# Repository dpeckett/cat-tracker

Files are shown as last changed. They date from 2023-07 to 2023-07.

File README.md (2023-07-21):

# Cat Tracker

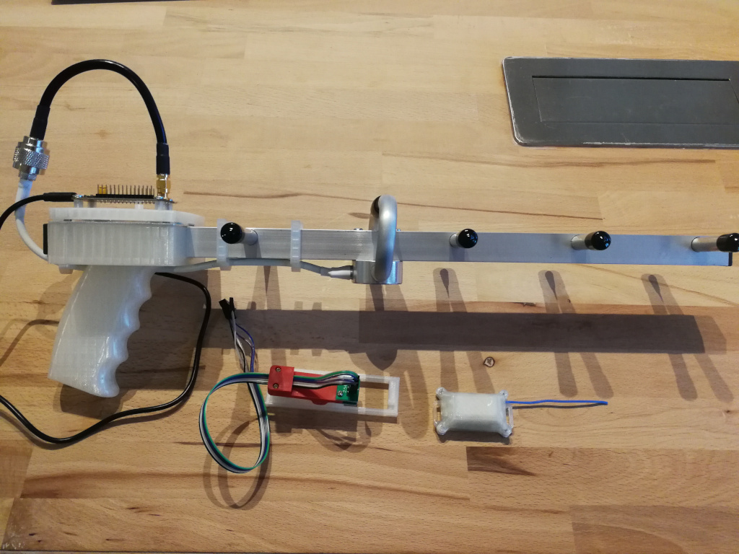
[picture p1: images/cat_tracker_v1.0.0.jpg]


An active RFID system for locating free roaming pets / wildlife. Uses a compact handheld radio direction finding receiver rather than GPS (due to power budget and the need for real-time updates). Kind of a modern take on a traditional wildlife tracker.

## Backstory

My wife and I adopted a free roaming snow bengal cat from a former neighbor. She's a very naughty cat and often decides she wants to spend extended time away from us in the giant wooded park next door.

I've spent many a late night walking in the woods with a kibble bag trying to get her to come home for dinner. I can usually locate her but it's a gigantic PITA.

It would be nice to have a real time GPS position but the commercial tracking collars are bulky (she's a tiny cat), expensive (ongoing fees), and have limited battery life. Of course there is the air tag and tile products, which I think are probably amazing in an urban area but our cat is often found in the dense woods far away from other people.

None of the existing solutions satisfied me so I decided to build my own. It had to be very compact, have a long battery life (months or years), and no ongoing costs.

## Notes

### Edit the Radio Configuration For Your Region

If you are outside the EU you will probably need to modify the radio configuration in [firmware/CatTracker/Base/subghz_radio.h](./firmware/CatTracker/Base/subghz_radio.h) to match your legislative region.

### To Unlock A STM32WLExx

Telnet into the OpenOCD server:

```
telnet localhost 4444
```

And run the following commands:

```
stm32l4x unlock 0
# Clear FLASH_OPTR
stm32l4x option_write 0 0x20 0xbffff0aa
# Power cycle the device
halt
stm32l4x mass_erase 0
```

### To Read The Unique ID From A STM32WLExx

Telnet into the OpenOCD server:

```
telnet localhost 4444
```

And run the following commands:

```
mdw 0x1FFF7590
```

## Errata

### EBYTE E77-900M22S Dev Boards

My boards arrived with a capacitor missing from the lowpass filter before the SMA jack. This meant the antenna jack was completely disconnected.

### PCB

The footprint for the battery holder needs a larger keep out area so that the center pad makes good contact. I temporarily resolved this by raising the pad with some additional solder.

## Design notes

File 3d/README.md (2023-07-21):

# Solid Models

This directory contains the solid models for the 3D printed parts of the
project. The models are designed in [OpenSCAD](http://www.openscad.org/).

## Parts

The following parts are included:

* `programming_jig.scad` - A jig to hold the PCB in place while programming (using a modified [3x2 pogo pin clip](https://aliexpress.com/item/1005003705632078.html)).
* `tracker_case.scad` - A case for holding the tracker PCB and battery.
* `tracker_case_lid.scad` - A lid for the tracker case.

## Notes

The lid and case of the tracker are affixed using four 2.9x6.5mm self-tapping screws.

To waterproof the tracker case I basically coated the entire assembly (and lid mating surface) in a layer of two-part silicone rubber. You could print the tracker out of resin but you'd have to design some kind of gasket (perhaps in a future revision).

## License

The models are licensed under the [Creative Commons Zero v1.0 Universal](https://creativecommons.org/publicdomain/zero/1.0/) license.

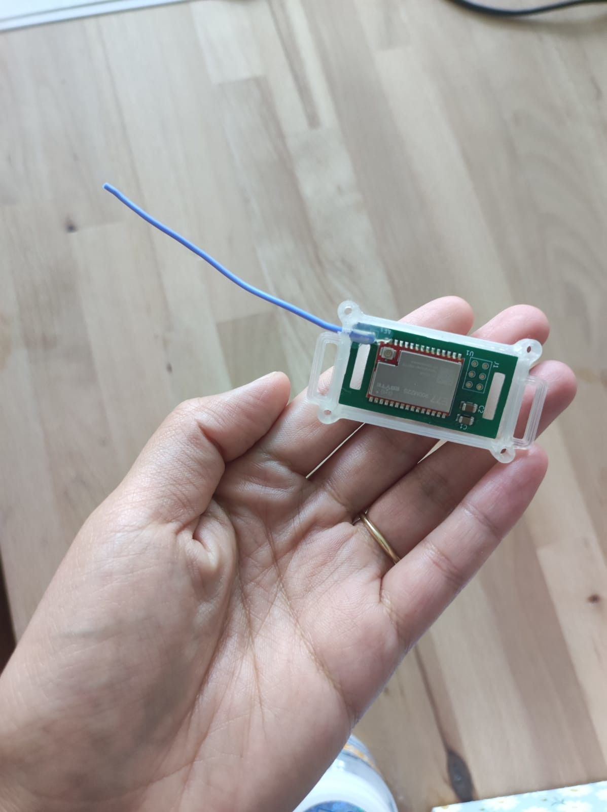
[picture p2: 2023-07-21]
images/cat_tracker_pcb_v1.0.0.jpg

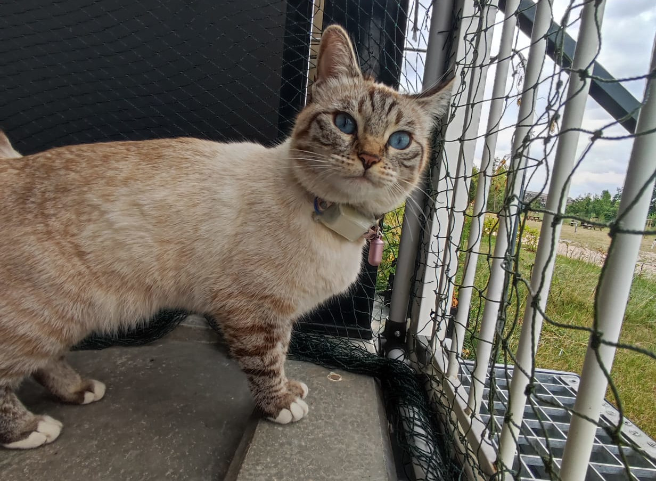
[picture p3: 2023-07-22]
images/cat_with_tracker_v1.0.0.jpg

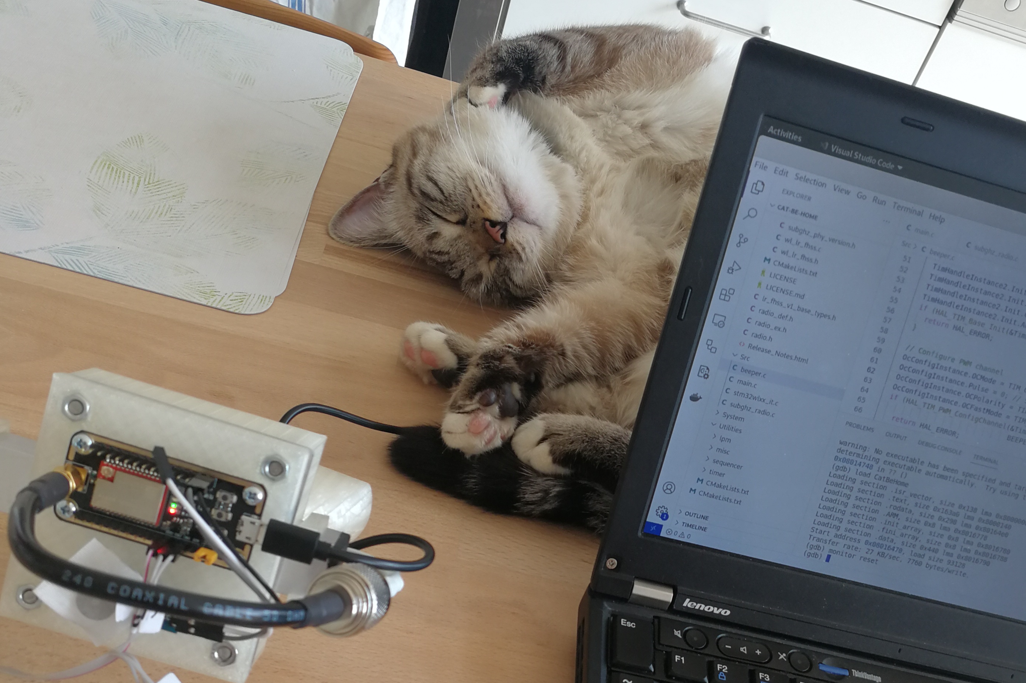
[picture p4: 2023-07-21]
images/cat_v1.0.0.jpg

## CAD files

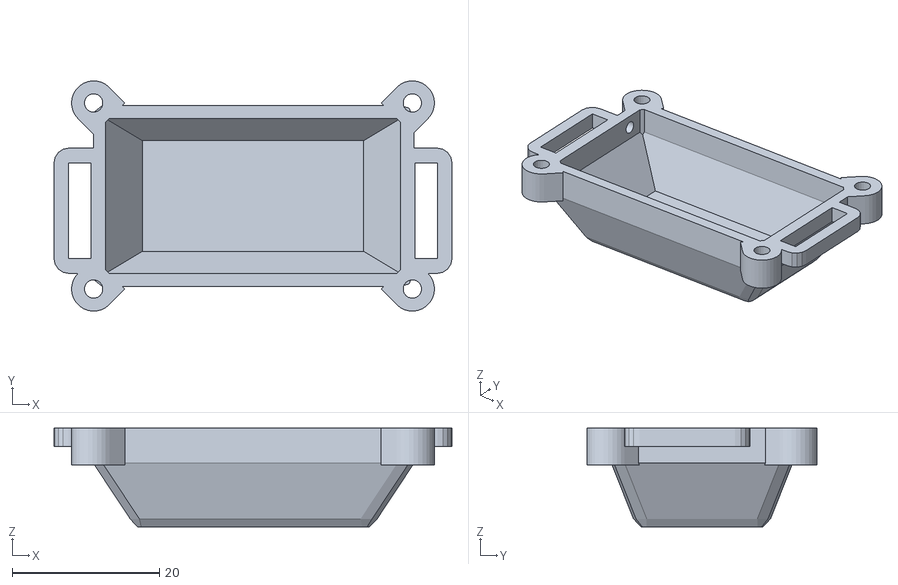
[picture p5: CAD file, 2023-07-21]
3d/tracker_case.stl
54.0 x 31.2 x 13.4

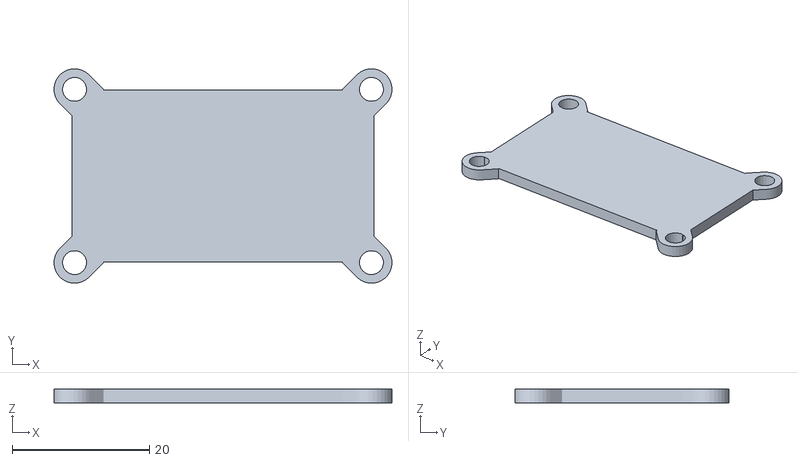
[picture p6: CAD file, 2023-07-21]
3d/tracker_case_lid.stl
49.2 x 31.2 x 2.00

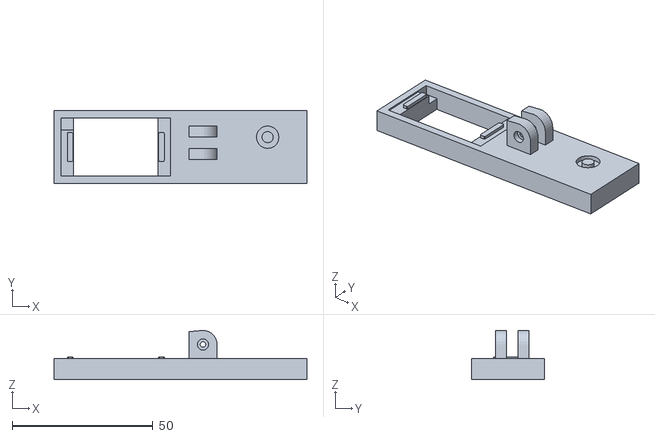
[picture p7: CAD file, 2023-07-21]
3d/programming_jig.stl
90.0 x 26.0 x 17.5

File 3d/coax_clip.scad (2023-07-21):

thickness = 3;
teeth_engage=2;
major_dim = 20.1;
coax_hole = 5.5;

extendo = 0;

linear_extrude(height=6) union() {
    difference() {
      square([major_dim + 2*thickness, major_dim + thickness]);
      translate([thickness, 0, 0]) square([major_dim, major_dim]);
      translate([major_dim/2 + thickness - coax_hole/2, major_dim, 0]) square([coax_hole, thickness]);
    }

    polygon([[0, 0], [thickness + teeth_engage, 0], [thickness + teeth_engage, -0.5*thickness], [0, -2*thickness]]);

    polygon([[major_dim + 2*thickness, 0], [(major_dim + 2*thickness) - thickness - teeth_engage, 0], [(major_dim + 2*thickness) - thickness - teeth_engage, -0.5*thickness], [major_dim + 2*thickness, -2*thickness]]);

    translate([major_dim/2 + thickness, extendo + major_dim+thickness, 0]) difference() {
        circle(d=coax_hole + 2*thickness, $fn = 20);
        circle(d=coax_hole, $fn = 20);
        translate([-(coax_hole + 2*thickness)/2, -2 *thickness]) square([coax_hole + 2*thickness, 2*thickness]);
    }
    
    translate([major_dim/2 - coax_hole/2, major_dim+thickness, 0])square([thickness, extendo]);
    
    translate([major_dim/2 + coax_hole/2 + thickness, major_dim+thickness, 0])square([thickness, extendo]);
}

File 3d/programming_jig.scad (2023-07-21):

difference() {
  cube([90, 26, 7.5]);
    
  translate([2.5, (26-20.5)/2, 7]) cube([39, 20.5, 0.5]);
  translate([7, (26-20.5)/2, 0]) cube([30, 20.5, 7.5]);
    
  translate([2.5, 19, 4]) cube([4.5, 4.5, 3]);
    
  translate([76, 16.5, 6])difference() {
    cylinder(d=8, h=1.5, $fn=20);
    cylinder(d=4, h=1.5, $fn=20);
  }
}

minkowski() {
  translate([5.25, 8.25, 7]) cube([1, 9.5, 0.5]);
  cylinder(d=1, h=0.5, $fn=10);
}

minkowski() {
  translate([5 + 32 + 0.75, 8.25, 7]) cube([1, 9.5, 0.5]);
  cylinder(d=1, h=0.5, $fn=10);
}

translate([53, 8.5, 7.5]) difference() {
  union() {
    translate([0, 0, 5]) rotate(a = [-90, 0, 0]) cylinder(d = 10, h = 12, $fn = 30);
    translate([-5, 0, 0]) cube([10, 12, 5]);
   
    // limit the rotation to 5 deg, to keep the spring retained.
    x = 5*(1 - tan(5));
    translate([0, 0, 5]) rotate(a = [-90, -180, 0])  linear_extrude(height = 12) polygon([[0, 0], [5, 0], [5, x], [0, 5]]);
  }
  
  translate([0, 0, 5]) rotate(a = [-90, 0, 0]) cylinder(d = 4, h = 2, $fn = 30);
  
  translate([0, 0, 5]) rotate(a = [-90, 0, 0]) cylinder(d = 2, h = 12, $fn = 16);
  translate([-5, 4, 0]) cube([10,4,10]);
}

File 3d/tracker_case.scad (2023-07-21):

thickness = 2;

case();
//lid();

module lid() {
  difference() {
    translate([0, 0, thickness/2]) cube([40 + 2*thickness, 21 + 2*thickness, thickness], center=true);
      
     // clearance for the screw ears.
    translate([-21.25, 12.25, 0]) cylinder(d = 3, h = thickness, $fn = 10);
    translate([-21.25, -12.25, 0]) cylinder(d = 3, h = thickness, $fn = 10);
    translate([21.25, 12.25, 0]) cylinder(d = 3, h = thickness, $fn = 10);
    translate([21.25, -12.25, 0]) cylinder(d = 3, h = thickness, $fn = 10);
  }
 
  // Screw ears
  translate([-19.5, 10.5, 0]) rotate(a = [0, 0, 45]) screw_ear(height = thickness, diameter = 3.5);
  translate([-19.5, -10.5, 0]) rotate(a = [0, 0, 135]) screw_ear(height = thickness, diameter = 3.5);
  translate([19.5, 10.5, 0]) rotate(a = [0, 0, -45]) screw_ear(height = thickness, diameter = 3.5);
  translate([19.5, -10.5, 0]) rotate(a = [0, 0, -135]) screw_ear(height = thickness, diameter = 3.5);
}

module case() {
  difference() {
    union() {
      minkowski() {
        union() {
          inner();
          translate([0, 0, 7.5 + (4+thickness)/2])        cube([40, 21, 4 + thickness], center = true);
        }
        sphere(r =  thickness);
      }
    }
  
    inner();
  
    // slice the top off clean.
    translate([0, 0, 7.5 + 2 * thickness + (11/2)]) cube([50, 50, 11], center = true);

    // clearance for the screw ears.
    translate([-21.25, 12.25, 7]) cylinder(d = 3, h = 5, $fn = 10);
    translate([-21.25, -12.25, 7]) cylinder(d = 3, h = 5, $fn = 10);
    translate([21.25, 12.25, 7]) cylinder(d = 3, h = 5, $fn = 10);
    translate([21.25, -12.25, 7]) cylinder(d = 3, h = 5, $fn = 10);
  
    // The antenna hole.
    translate([-21.75, 7.5, 9.5])rotate(a = [0, 90, 0]) cylinder(d = 1.9, h = thickness, $fn = 30);
  }

  // Screw ears
  translate([-19.5, 10.5, 6.5]) rotate(a = [0, 0, 45]) screw_ear();
  translate([-19.5, -10.5, 6.5]) rotate(a = [0, 0, 135]) screw_ear();
  translate([19.5, 10.5, 6.5]) rotate(a = [0, 0, -45]) screw_ear();
  translate([19.5, -10.5, 6.5]) rotate(a = [0, 0, -135]) screw_ear();

  translate([-23.5, -2, 9]) collar_ring(height=2.5);
  translate([23.5, -2, 9]) rotate(a = [0, 0, 180]) collar_ring(height=2.5);
}

module inner() {
  hull() {
    cube([30, 15, 0.1], center = true);
    translate([0, 0, 7.5 + 4/2]) cube([40, 21, 4], center = true);
  }
}

module screw_ear(height = 5, diameter = 2.5) {
    difference() {
      union() {
        translate([0, 6/2, 0]) cylinder(d = 6, h = height, $fn=30);
        translate([-6/2, 0, 0]) cube([6, 6/2, height]);
      }
      
      translate([0, 6/2, 0]) cylinder(d = diameter, h = height, $fn = 20);
    }
}

module collar_ring(height = 5) {
  linear_extrude(height = height) difference() {
    union() {
      minkowski() {
        square([3, 13], center=true);
        circle(r = thickness, $fn = 16);
      }
      translate([0, -(13 + 2*thickness)/2, 0]) square([3/2 + thickness, 13 + 2*thickness]);
    }
    square([3, 13], center=true);
  }
}

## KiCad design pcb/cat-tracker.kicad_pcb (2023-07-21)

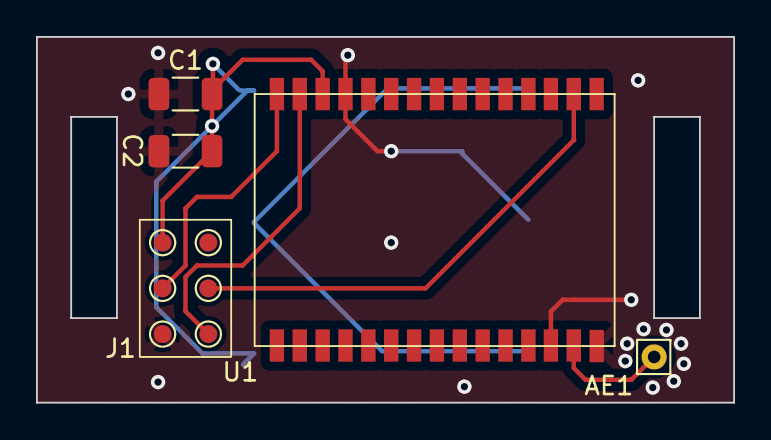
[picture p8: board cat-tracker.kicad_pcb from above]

Board: 2 copper layers, 38.7 x 20.3 mm, 5 parts (0 on the bottom side), 6 nets.

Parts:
AE1: Antenna; Pin_D0.7mm_L6.5mm_W1.8mm_FlatFork
C1: 1uF; C_1206_3216Metric
C2: 10uF; C_1206_3216Metric
J1: SWD
U1: E07-900M10S

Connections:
GND: C1.2, C2.2, J1.3, U1.13 (GND), U1.15 (GND), U1.27 (GND)
unnamed: AE1.1 (A), U1.14 (ANT)
unnamed: J1.2, U1.30 (SWCLK)
unnamed: J1.4, U1.29 (SWDIO)
unnamed: J1.5, U1.17 (NRST)
VDD: C1.1, C2.1, J1.1, U1.28 (VDD)

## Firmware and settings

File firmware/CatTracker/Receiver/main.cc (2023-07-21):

#include <array>
#include <cstdlib>
#include <cstring>

#include "main.h"
#include "packet_handler.h"
#include "subghz_radio.h"
#include "time_util.h"
#include "uart.h"

namespace CatTracker {

void radioProcessEvent();
void receiveNextPacket(void *Context);

HAL_StatusTypeDef configureSystemClock();

UTIL_TIMER_Object_t RxTimer;

extern "C" int main() {
  if (HAL_Init() != HAL_OK) {
    Error_Handler();
  }

  if (configureSystemClock() != HAL_OK) {
    Error_Handler();
  }

  // Initialize timer and RTC.
  UTIL_TIMER_Init();

  if (UART::init() != HAL_OK) {
    Error_Handler();
  }

  if (SUBGHZRadio::init() != HAL_OK) {
    Error_Handler();
  }

  // Register radio event handler.
  UTIL_SEQ_RegTask((1 << CFG_SEQ_Task_SubGHz_ProcessEvent), UTIL_SEQ_RFU,
                   radioProcessEvent);

  printf("Listening for beacons...\r\n");

  // Kick off the radio event loop.
  receiveNextPacket(nullptr);

  for (;;) {
    UTIL_SEQ_Run(UTIL_SEQ_DEFAULT);
  }

  return 0;
}

void radioProcessEvent() {
  const auto EventType = SUBGHZRadio::getEventType();
  const auto PacketHandler = getPacketHandler();
  SUBGHZRadio::Packet TxPacket;

  if (EventType == SUBGHZRadio::EventType::Rx) {
    if (PacketHandler(SUBGHZRadio::getReceivedPacket(), &TxPacket)) {
      SUBGHZRadio::sendPacket(&TxPacket);
      return;
    }
  }

  UTIL_TIMER_Create(&RxTimer, 0, UTIL_TIMER_ONESHOT, receiveNextPacket,
                    nullptr);
  UTIL_TIMER_Start(&RxTimer);
}

void receiveNextPacket(void *Context) { SUBGHZRadio::receivePacket(0); }

HAL_StatusTypeDef configureSystemClock() {
  RCC_OscInitTypeDef RCC_OscInitStruct = {0};
  RCC_ClkInitTypeDef RCC_ClkInitStruct = {0};

  // Configure LSE Drive Capability.
  HAL_PWR_EnableBkUpAccess();
  __HAL_RCC_LSEDRIVE_CONFIG(RCC_LSEDRIVE_LOW);

  // Configure the main internal regulator output voltage.
  __HAL_PWR_VOLTAGESCALING_CONFIG(PWR_REGULATOR_VOLTAGE_SCALE1);

  // Initializes the CPU, AHB and APB busses clocks.
  RCC_OscInitStruct.OscillatorType =
      RCC_OSCILLATORTYPE_HSE | RCC_OSCILLATORTYPE_LSE;
  RCC_OscInitStruct.HSEState = RCC_HSE_ON;
  RCC_OscInitStruct.LSEState = RCC_LSE_ON;
  RCC_OscInitStruct.HSEDiv = RCC_HSE_DIV1;
  RCC_OscInitStruct.PLL.PLLState = RCC_PLL_ON;
  RCC_OscInitStruct.PLL.PLLSource = RCC_PLLSOURCE_HSE;
  RCC_OscInitStruct.PLL.PLLM = RCC_PLLM_DIV2;
  RCC_OscInitStruct.PLL.PLLN = 12;
  RCC_OscInitStruct.PLL.PLLP = RCC_PLLP_DIV2;
  RCC_OscInitStruct.PLL.PLLR = RCC_PLLR_DIV4;
  RCC_OscInitStruct.PLL.PLLQ = RCC_PLLQ_DIV2;
  if (HAL_RCC_OscConfig(&RCC_OscInitStruct) != HAL_OK) {
    return HAL_ERROR;
  }

  // Configure the SYSCLKSource, HCLK, PCLK1 and PCLK2 clocks dividers.
  RCC_ClkInitStruct.ClockType = RCC_CLOCKTYPE_HCLK3 | RCC_CLOCKTYPE_HCLK |
                                RCC_CLOCKTYPE_SYSCLK | RCC_CLOCKTYPE_PCLK1 |
                                RCC_CLOCKTYPE_PCLK2;
  RCC_ClkInitStruct.SYSCLKSource = RCC_SYSCLKSOURCE_PLLCLK;
  RCC_ClkInitStruct.AHBCLKDivider = RCC_SYSCLK_DIV1;
  RCC_ClkInitStruct.APB1CLKDivider = RCC_HCLK_DIV1;
  RCC_ClkInitStruct.APB2CLKDivider = RCC_HCLK_DIV1;
  RCC_ClkInitStruct.AHBCLK3Divider = RCC_SYSCLK_DIV1;
  if (HAL_RCC_ClockConfig(&RCC_ClkInitStruct, FLASH_LATENCY_2) != HAL_OK) {
    return HAL_ERROR;
  }

  // Ensure that MSI is wake-up system clock.
  __HAL_RCC_WAKEUPSTOP_CLK_CONFIG(RCC_STOP_WAKEUPCLOCK_MSI);

  return HAL_OK;
}

void Error_Handler() { HAL_NVIC_SystemReset(); }

} // namespace CatTracker

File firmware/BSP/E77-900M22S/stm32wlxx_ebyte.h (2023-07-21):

/*
 * Copyright (c) 2020-2021 STMicroelectronics.
 * All rights reserved.
 *
 * This software is licensed under terms that can be found in the LICENSE file
 * in the root directory of this software component.
 * If no LICENSE file comes with this software, it is provided AS-IS.
 */

#ifndef STM32WLXX_EBYTE_H
#define STM32WLXX_EBYTE_H

#ifdef __cplusplus
extern "C" {
#endif

#include "stm32wlxx_ebyte_conf.h"
#include "stm32wlxx_ebyte_errno.h"

#if (USE_BSP_COM_FEATURE > 0)
#if (USE_COM_LOG > 0)
#ifndef __GNUC__
#include "stdio.h"
#endif
#endif
#endif

typedef enum {
  LED1 = 0,
  LED2 = 1,
  LED3 = 2,
  /* Color led aliases */
  LED_BLUE = LED1,
  LED_GREEN = LED2,
  LED_RED = LED3
} Led_TypeDef;

typedef enum {
  BUTTON_SW1 = 0,
  BUTTON_SW2 = 1,
  BUTTON_SW3 = 2,
} Button_TypeDef;

typedef enum { BUTTON_MODE_GPIO = 0, BUTTON_MODE_EXTI = 1 } ButtonMode_TypeDef;

#if (USE_BSP_COM_FEATURE > 0)
typedef enum { COM1 = 0U, COMn } COM_TypeDef;

typedef enum {
  COM_STOPBITS_1 = UART_STOPBITS_1,
  COM_STOPBITS_2 = UART_STOPBITS_2,
} COM_StopBitsTypeDef;

typedef enum {
  COM_PARITY_NONE = UART_PARITY_NONE,
  COM_PARITY_EVEN = UART_PARITY_EVEN,
  COM_PARITY_ODD = UART_PARITY_ODD,
} COM_ParityTypeDef;

typedef enum {
  COM_HWCONTROL_NONE = UART_HWCONTROL_NONE,
  COM_HWCONTROL_RTS = UART_HWCONTROL_RTS,
  COM_HWCONTROL_CTS = UART_HWCONTROL_CTS,
  COM_HWCONTROL_RTS_CTS = UART_HWCONTROL_RTS_CTS,
} COM_HwFlowCtlTypeDef;

typedef enum {
  COM_WORDLENGTH_7B = UART_WORDLENGTH_7B,
  COM_WORDLENGTH_8B = UART_WORDLENGTH_8B,
  COM_WORDLENGTH_9B = UART_WORDLENGTH_9B,
} COM_WordLengthTypeDef;

typedef struct {
  uint32_t BaudRate;
  COM_WordLengthTypeDef WordLength;
  COM_StopBitsTypeDef StopBits;
  COM_ParityTypeDef Parity;
  COM_HwFlowCtlTypeDef HwFlowCtl;
} COM_InitTypeDef;

#if (USE_HAL_UART_REGISTER_CALLBACKS == 1)
typedef struct {
  pUART_CallbackTypeDef pMspInitCb;
  pUART_CallbackTypeDef pMspDeInitCb;
} BSP_COM_Cb_t;
#endif /* (USE_HAL_UART_REGISTER_CALLBACKS == 1) */
#endif /* (USE_BSP_COM_FEATURE > 0) */

typedef enum {
  ABSENT = 0,
  PRESENT = 1,
} Presence_TypeDef;

/**
 * @brief STM32WLXX EBYTE BSP Driver version number
 */
#define __STM32WLXX_EBYTE_BSP_VERSION_MAIN (0x01U) /*!< [31:24] main version   \
                                                    */
#define __STM32WLXX_EBYTE_BSP_VERSION_SUB1 (0x03U) /*!< [23:16] sub1 version   \
                                                    */
#define __STM32WLXX_EBYTE_BSP_VERSION_SUB2 (0x00U) /*!< [15:8]  sub2 version   \
                                                    */
#define __STM32WLXX_EBYTE_BSP_VERSION_RC                                       \
  (0x00U) /*!< [7:0]  release candidate */
#define __STM32WLXX_EBYTE_BSP_VERSION                                          \
  ((__STM32WLXX_EBYTE_BSP_VERSION_MAIN << 24) |                                \
   (__STM32WLXX_EBYTE_BSP_VERSION_SUB1 << 16) |                                \
   (__STM32WLXX_EBYTE_BSP_VERSION_SUB2 << 8) |                                 \
   (__STM32WLXX_EBYTE_BSP_VERSION_RC))

/**
 * @brief Define for STM32WLXX_EBYTE board
 */
#if !defined(USE_STM32WLXX_EBYTE)
#define USE_STM32WLXX_EBYTE
#endif

#define LEDn 3

#define LED1_PIN GPIO_PIN_5
#define LED1_GPIO_PORT GPIOB
#define LED1_GPIO_CLK_ENABLE() __HAL_RCC_GPIOB_CLK_ENABLE()
#define LED1_GPIO_CLK_DISABLE() __HAL_RCC_GPIOB_CLK_DISABLE()

#define LED2_PIN GPIO_PIN_4
#define LED2_GPIO_PORT GPIOB
#define LED2_GPIO_CLK_ENABLE() __HAL_RCC_GPIOB_CLK_ENABLE()
#define LED2_GPIO_CLK_DISABLE() __HAL_RCC_GPIOB_CLK_DISABLE()

#define LED3_PIN GPIO_PIN_3
#define LED3_GPIO_PORT GPIOB
#define LED3_GPIO_CLK_ENABLE() __HAL_RCC_GPIOB_CLK_ENABLE()
#define LED3_GPIO_CLK_DISABLE() __HAL_RCC_GPIOB_CLK_DISABLE()

#define LEDx_GPIO_CLK_ENABLE(__INDEX__)                                        \
  __HAL_RCC_GPIOB_CLK_ENABLE() /* All Led on same port */
#define LEDx_GPIO_CLK_DISABLE(__INDEX__)                                       \
  __HAL_RCC_GPIOB_CLK_DISABLE() /* All Led on same port */

#define BUTTONn 3

/**
 * @brief Key push-buttons
 */
#define BUTTON_SW1_PIN GPIO_PIN_0
#define BUTTON_SW1_GPIO_PORT GPIOA
#define BUTTON_SW1_GPIO_CLK_ENABLE() __HAL_RCC_GPIOA_CLK_ENABLE()
#define BUTTON_SW1_GPIO_CLK_DISABLE() __HAL_RCC_GPIOA_CLK_DISABLE()
#define BUTTON_SW1_EXTI_LINE EXTI_LINE_0
#ifdef CORE_CM0PLUS
#define BUTTON_SW1_EXTI_IRQn EXTI1_0_IRQn
#else
#define BUTTON_SW1_EXTI_IRQn EXTI0_IRQn
#endif
#define H_EXTI_0 hpb_exti[BUTTON_SW1]

#define BUTTON_SW2_PIN GPIO_PIN_1
#define BUTTON_SW2_GPIO_PORT GPIOA
#define BUTTON_SW2_GPIO_CLK_ENABLE() __HAL_RCC_GPIOA_CLK_ENABLE()
#define BUTTON_SW2_GPIO_CLK_DISABLE() __HAL_RCC_GPIOA_CLK_DISABLE()
#define BUTTON_SW2_EXTI_LINE EXTI_LINE_1
#ifdef CORE_CM0PLUS
#define BUTTON_SW2_EXTI_IRQn EXTI1_0_IRQn
#else
#define BUTTON_SW2_EXTI_IRQn EXTI1_IRQn
#endif
#define H_EXTI_1 hpb_exti[BUTTON_SW2]

#define BUTTON_SW3_PIN GPIO_PIN_4
#define BUTTON_SW3_GPIO_PORT GPIOA
#define BUTTON_SW3_GPIO_CLK_ENABLE() __HAL_RCC_GPIOA_CLK_ENABLE()
#define BUTTON_SW3_GPIO_CLK_DISABLE()           __HAL_RCC_GPIOA_CLK_DISABLE(
#define BUTTON_SW3_EXTI_LINE EXTI_LINE_4
#ifdef CORE_CM0PLUS
#define BUTTON_SW3_EXTI_IRQn EXTI15_4_IRQn
#else
#define BUTTON_SW3_EXTI_IRQn EXTI4_IRQn
#endif
#define H_EXTI_6 hpb_exti[BUTTON_SW3]

#define BUTTONx_GPIO_CLK_ENABLE(__INDEX__)                                     \
  do {                                                                         \
    if ((__INDEX__) == BUTTON_SW1)                                             \
      BUTTON_SW1_GPIO_CLK_ENABLE();                                            \
    else if ((__INDEX__) == BUTTON_SW2)                                        \
      BUTTON_SW2_GPIO_CLK_ENABLE();                                            \
    else if ((__INDEX__) == BUTTON_SW3)                                        \
      BUTTON_SW3_GPIO_CLK_ENABLE();                                            \
  } while (0)

#define BUTTONx_GPIO_CLK_DISABLE(__INDEX__)                                    \
  do {                                                                         \
    if ((__INDEX__) == BUTTON_SW1)                                             \
      BUTTON_SW1_GPIO_CLK_DISABLE();                                           \
    else if ((__INDEX__) == BUTTON_SW2)                                        \
      BUTTON_SW2_GPIO_CLK_DISABLE();                                           \
    else if ((__INDEX__) == BUTTON_SW3)                                        \
      BUTTON_SW3_GPIO_CLK_DISABLE();                                           \
  } while (0)

#if (USE_BSP_COM_FEATURE > 0)
#define COM1_UART LPUART1
#define COM1_CLK_ENABLE() __HAL_RCC_LPUART1_CLK_ENABLE()
#define COM1_CLK_DISABLE() __HAL_RCC_LPUART1_CLK_DISABLE()

#define COM1_TX_PIN GPIO_PIN_2
#define COM1_TX_GPIO_PORT GPIOA
#define COM1_TX_GPIO_CLK_ENABLE() __HAL_RCC_GPIOA_CLK_ENABLE()
#define COM1_TX_GPIO_CLK_DISABLE() __HAL_RCC_GPIOA_CLK_DISABLE()
#define COM1_TX_AF GPIO_AF8_LPUART1
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
